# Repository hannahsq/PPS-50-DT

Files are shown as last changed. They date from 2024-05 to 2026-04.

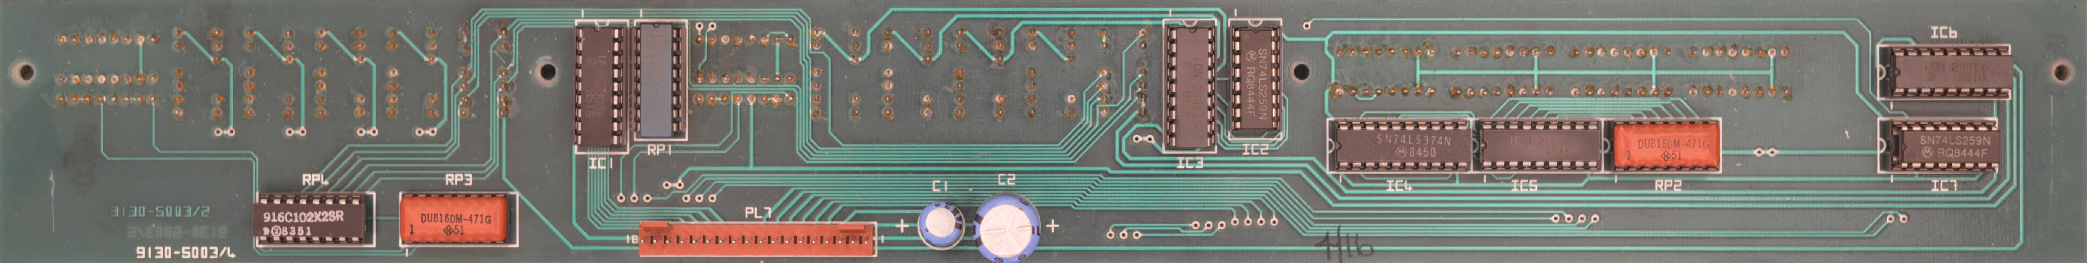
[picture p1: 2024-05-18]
pcb_photos/display_bottom.png

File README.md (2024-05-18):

# PPS-50-DT
Reverse engineered schematics and code for the Prism Instruments PPS 50 DT power supply

Everything is in a very rough state at the moment but I wanted to put this up there in case anyone finds it useful.

The disassembly is slow going, full of placeholder stuff, and likely riddled with mistakes. I will probably switch to ghidra from f9dasm when 6800 support is added.

The schematic is only partially complete but what is there should be mostly accurate.

## Disassembly
This project currently uses f9dasm (available [here][1]) and `disassemble.py` expects to find either f9dasm on linux or f9dasm.exe on windows at ../tools/f9dasm[.exe].

[1]: https://github.com/Arakula/f9dasm

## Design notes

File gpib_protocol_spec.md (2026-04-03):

# IEEE-488 (GPIB) Protocol Specification
## Reverse-Engineered from Firmware — Dual-Channel Power Supply

---

## 1. System Architecture

The instrument contains two 6802 processors connected via an optically-isolated UART link:

- **Primary Controller** — Manages the analog hardware: DACs, ADCs, analog switches,
  voltage/current regulation loops. Runs from 4K PROM.
- **GPIB Controller** — Handles all IEEE-488 bus communication. Contains an MC68488
  GPIA (General Purpose Interface Adapter) for GPIB bus management and an MC6850 ACIA
  for the inter-processor UART link.

The GPIB controller parses commands received over the IEEE-488 bus, translates them into
3-byte UART messages, sends them to the primary controller, receives 3-byte responses,
and formats the results back into GPIB response strings.

```
                 OPTOCOUPLERS
  IEEE-488       ┌──────────┐        ANALOG
  GPIB Bus ──── MC68488 ── ACIA ══════════ ACIA ── 6802 ──── DACs/ADCs
                 6802       │  UART LINK  │        Primary   Analog Switches
                 GPIB Ctrl  └──────────┘         Controller  Voltage/Current
```

## 2. GPIB Bus Configuration

- **Address**: Set by DIP switch (5-bit, bits 4:0 of MC68488 Address Register)
- **Capabilities**: Talk and Listen
- **Serial Poll**: Supported (status byte in MC68488 SPR, SRQ assertion)
- **Device Clear**: Supported (DCAS handling)
- **Termination**: Commands terminated by CR (0x0D), LF (0x0A), or EOI
- **Character set**: Alphanumeric (A-Z, a-z, 0-9), period (.), CR, LF only.
  Characters ` ' + , - / : ; \ ` and all control characters are rejected.
- **Max command length**: 50 characters

## 3. Command Reference

All commands are ASCII strings terminated by CR, LF, or EOI. Commands are
case-sensitive — set commands use lowercase letters.

### 3.1 Set Voltage

Set the output voltage for a channel.

| Command | Description |
|---|---|
| `aXXXX` | Set Channel A voltage |
| `bXXXX` | Set Channel B voltage |

`XXXX` is a decimal number. The firmware parses up to 4 digits and converts to a 16-bit
binary value which is sent to the primary controller's DAC. The exact voltage scaling
depends on the DAC and analog circuitry (needs to be determined from the hardware).

The GPIB talk response includes a decimal point: `VSA XX.XX` or `VSB XX.XX`.

**Examples:**
```
a1250    → Set Channel A voltage to 12.50 (units TBD)
b0500    → Set Channel B voltage to 05.00
```

### 3.2 Set Current

Set the output current / current limit for a channel.

| Command | Description |
|---|---|
| `cXXXX` | Set Channel A current |
| `dXXXX` | Set Channel B current |

Same numeric format as voltage commands. Response format: `ISA XX.XX` or `ISB XX.XX`.

### 3.3 Set Voltage Override

| Command | Description |
|---|---|
| `iXXXX` | Set Channel A voltage override |
| `jXXXX` | Set Channel B voltage override |

Response format: `VOA XX.XX` or `VOB XX.XX`.

The exact meaning of "override" vs "set" needs confirmation from the analog hardware,
but likely sets the voltage directly bypassing any tracking or limit logic.

### 3.4 Set Current Override

| Command | Description |
|---|---|
| `kXXXX` | Set Channel A current override |
| `lXXXX` | Set Channel B current override |

Response format: `IOA XX.XX` or `IOB XX.XX`.

### 3.5 Set Voltage Limit

| Command | Description |
|---|---|
| `eXXXX` | Set Channel A voltage limit |
| `fXXXX` | Set Channel B voltage limit |

Response format: `VLA XXXXX` or `VLB XXXXX` (no decimal point — 5 digit integer).

### 3.6 Set Current Limit

| Command | Description |
|---|---|
| `gXXXX` | Set Channel A current limit |
| `hXXXX` | Set Channel B current limit |

Response format: `ILA XXXXX` or `ILB XXXXX` (no decimal point — 5 digit integer).

### 3.7 Query Status

| Command | Description |
|---|---|
| `q` | Query full instrument status |

Returns a multi-field response string:

```
[ChA_mode]/[ChB_mode]/[tracking]/[output]<CR><LF+EOI>
```

**Channel mode fields** (4 characters each):

| String | Meaning |
|---|---|
| `A CV` | Channel A — Constant Voltage mode |
| `A CC` | Channel A — Constant Current mode |
| `A IL` | Channel A — Current Limit active |
| `A VL` | Channel A — Voltage Limit active |
| `B CV` | Channel B — Constant Voltage mode |
| `B CC` | Channel B — Constant Current mode |
| `B IL` | Channel B — Current Limit active |
| `B VL` | Channel B — Voltage Limit active |

**Tracking field** (4 characters):

| String | Meaning |
|---|---|
| `T ON` | Tracking mode enabled (channels linked) |
| `TOFF` | Tracking mode disabled |

**Output field** (4-5 characters):

| String | Meaning |
|---|---|
| `OPON`  | Output enabled |
| `OPOFF` | Output disabled |

**Example response:**
```
A CV/B CC/TOFF/OPON
```
This indicates Channel A is in constant voltage mode, Channel B is in constant current
mode, tracking is off, and the output is enabled.

### 3.8 Read Error Status

| Command | Description |
|---|---|
| `r` | Read error/status register |

Returns:
```
ER R [status]<CR><LF+EOI>
```

On success: `ER R OK`
On error: `ER R [code]!` where `[code]` is a single error character (see Section 5).

Reading the error status clears it back to "OK".

### 3.9 Unknown/Invalid Commands

If an unrecognised command character is received, the instrument responds with:

```
[cmd] ??<CR><LF+EOI>
```

Where `[cmd]` is the character that was sent.

## 4. Command-Response Lookup Table

The firmware contains an explicit mapping from command characters to 3-letter response
codes. This table is used when building GPIB talk responses after a set command:

| Command | Response Code | Full Meaning |
|---|---|---|
| `a` | `VSA` | Voltage Set A |
| `b` | `VSB` | Voltage Set B |
| `c` | `ISA` | Current Set A |
| `d` | `ISB` | Current Set B |
| `e` | `VLA` | Voltage Limit A |
| `f` | `VLB` | Voltage Limit B |
| `g` | `ILA` | Current Limit A |
| `h` | `ILB` | Current Limit B |
| `i` | `VOA` | Voltage Override A |
| `j` | `VOB` | Voltage Override B |
| `k` | `IOA` | Current Override A |
| `l` | `IOB` | Current Override B |

Set commands (`a`-`d`, `i`-`l`) respond with a decimal-pointed value: `CODE XX.XX`
Limit commands (`e`-`h`) respond with an integer value: `CODE XXXXX`

Leading zeros are suppressed in responses.

## 5. Error / Status Codes

Single-character status codes used internally between the two processors and reported
via GPIB serial poll and the `r` (read status) command:

| Code | Hex  | Meaning |
|---|---|---|
| `OK` | $4F4B | No error — normal operation |
| `I`  | $49 | Internal error (from primary controller) |
| `J`  | $4A | NMI hardware fault (from GPIB controller NMI handler) |
| `K`  | $4B | UART communication error (inter-processor link failure) |
| `M`  | $4D | Syntax error (invalid character in command) |
| `N`  | $4E | Value out of range (from primary controller) |
| `O`  | $4F | Command overflow (exceeded 50-character limit) |

### Serial Poll Status Byte

The instrument supports IEEE-488 serial polling. The serial poll response byte (MC68488
SPR register) contains the same single-character error code. When an error occurs:

1. The error code is written to the MC68488 Serial Poll Register
2. This asserts SRQ on the GPIB bus
3. The controller can serial-poll to read the status byte
4. After the poll is serviced, the status is cleared

The SRQ/poll mechanism is also used for status change notifications (e.g., when a
channel transitions between CV/CC modes).

## 6. Inter-Processor UART Protocol

### 6.1 Physical Layer

- **Baud rate**: Determined by MC6850 ACIA configuration — clock divider set to /16
- **Format**: 8 data bits, 2 stop bits, no parity
- **Isolation**: Optocoupler-isolated
- **Flow control**: Software (polling with timeout)

### 6.2 Message Format

All exchanges are 3 bytes in each direction, preceded by a handshake byte:

```
GPIB Controller → Primary Controller:
  [handshake: link_state_flags byte]
  [wait for acknowledgment]
  [byte 0: command character]
  [byte 1: data high byte]
  [byte 2: data low byte]

Primary Controller → GPIB Controller:
  [acknowledgment byte]
  [byte 0: command echo | 0x80 on error]
  [byte 1: response data high]
  [byte 2: response data low]
```

### 6.3 Handshake Protocol

1. GPIB controller sends `link_state_flags` byte
2. Primary controller echoes back with framing bits (masked by 0x30)
3. GPIB controller waits for echo with framing bits cleared
4. 3-byte command is sent
5. 3-byte response is received
6. Response byte 0 is compared against sent command (with bit 7 masked)
7. If mismatch, retry up to 5 times

### 6.4 Framing Byte Types

The UART link uses bits 5:4 of each byte to distinguish frame types:

| Bits 5:4 | Value | Meaning |
|---|---|---|
| `00` | $00 | Handshake acknowledgment (no framing) |
| `01` | $10 | Status frame (mode change notification) |
| `10` | $20 | Device status update (channel modes, tracking, output) |
| `11` | $30 | Link state update |

### 6.5 Asynchronous Status Updates

The primary controller can send unsolicited status updates to the GPIB controller
between command exchanges. These are received by the `uart_poll_rx` function in the
main loop:

- **Status update (0x20 frame)**: Carries the device status byte which encodes channel
  modes (CV/CC/IL/VL), tracking state, and output state.
- **Link state (0x30 frame)**: Carries link synchronisation state.
- **Error codes (0x10 frame with payload)**: Single-character error notifications
  ('I'=internal, 'J'=NMI, 'T'=talker, 'S'=serial poll).

### 6.6 Primary Controller Command Dispatch

The primary controller dispatches on the command byte (byte 0) minus 0x41 ('A') as an
index into a jump table. The command mapping is:

| Byte 0 Range | Jump Table Index | Function |
|---|---|---|
| `A`-`H` ($41-$48) | 0-7 | Set voltage/current (value in bytes 1:2) |
| `I`-`L` ($49-$4C) | 8-11 | Set limits |
| `Q` ($51) | 16 | Enable tracking |
| `R` ($52) | 17 | Disable tracking |
| `S` ($53) | 18 | Serial poll acknowledgment |
| `T` ($54) | 19 | Talker state update |
| `U` ($55) | 20 | Status update request |
| `V` ($56) | 21 | Device clear notification |
| `Y` ($59) | 24 | Enable output |
| `Z` ($5A) | 25 | Disable output |
| `a`-`l` ($61-$6C) | 32-43 | Readback (returns current actual values) |
| `q` ($71) | 48 | Query state |
| `r` ($72) | 49 | Read status |

## 7. Numeric Value Format

### 7.1 Input Parsing

Numeric arguments are parsed as decimal ASCII digit strings (up to 4 digits). The
firmware converts using a repeated-subtraction division algorithm with a powers-of-ten
table:

```
Powers: 10000 ($2710), 1000 ($03E8), 100 ($0064), 10 ($000A)
```

The resulting 16-bit binary value is transmitted to the primary controller in bytes 1:2
of the UART message (big-endian).

### 7.2 Output Formatting

For GPIB talk responses, 16-bit binary values from the primary controller are converted
back to decimal ASCII using the same powers-of-ten table. The format depends on the
command type:

- **Voltage/Current set commands** (a-d, i-l): `XX.XX` with decimal point after digit 2
- **Limit commands** (e-h): `XXXXX` as a plain integer

Leading zeros are suppressed (replaced with spaces).

## 8. Implementation Notes for Building a GPIB Controller

### 8.1 Minimum Viable Controller

To control the instrument over GPIB, a controller needs to:

1. Address the instrument as a listener
2. Send a command string terminated by CR or LF (with or without EOI)
3. For queries, address the instrument as a talker and read until EOI

### 8.2 Example Session

```
Controller → Instrument (Listen):  "a1250\r"     Set Ch A voltage to 12.50
Controller → Instrument (Talk):    reads →        "VSA 12.50\n" (with EOI)
Controller → Instrument (Listen):  "c0300\r"     Set Ch A current to 03.00
Controller → Instrument (Talk):    reads →        "ISA  3.00\n" (with EOI)
Controller → Instrument (Listen):  "q\r"         Query status
Controller → Instrument (Talk):    reads →        "A CV/B CV/TOFF/OPON\n"
Controller → Instrument (Listen):  "r\r"         Read error status
Controller → Instrument (Talk):    reads →        "ER R OK\n"
```

### 8.3 Timing Considerations

- The GPIB controller polls (not interrupt-driven for GPIB), so it will respond at the
  main loop rate.
- UART exchanges with the primary controller include a 0xFFFF-iteration timeout loop
  and up to 5 retries.
- The `q` (query) command waits for status synchronisation between the two processors
  before responding, which may introduce additional latency.

### 8.4 Unresolved Items

- **DAC value scaling**: The exact relationship between the numeric command values and
  physical voltage/current depends on the DAC resolution and analog front-end scaling.
  This needs to be determined from the hardware (DAC IC, reference voltage, op-amp gain).
- **"Override" commands (i-l)**: The distinction between "set" (a-d) and "override"
  (i-l) commands is not fully clear from firmware alone. Likely bypasses tracking or
  limit enforcement.
- **Front panel interaction**: The primary controller also handles keyboard/display via
  PIAs (IC18, IC19, IC20). GPIB commands and front panel controls may interact — the
  firmware appears to manage this via the M0x53 state byte.

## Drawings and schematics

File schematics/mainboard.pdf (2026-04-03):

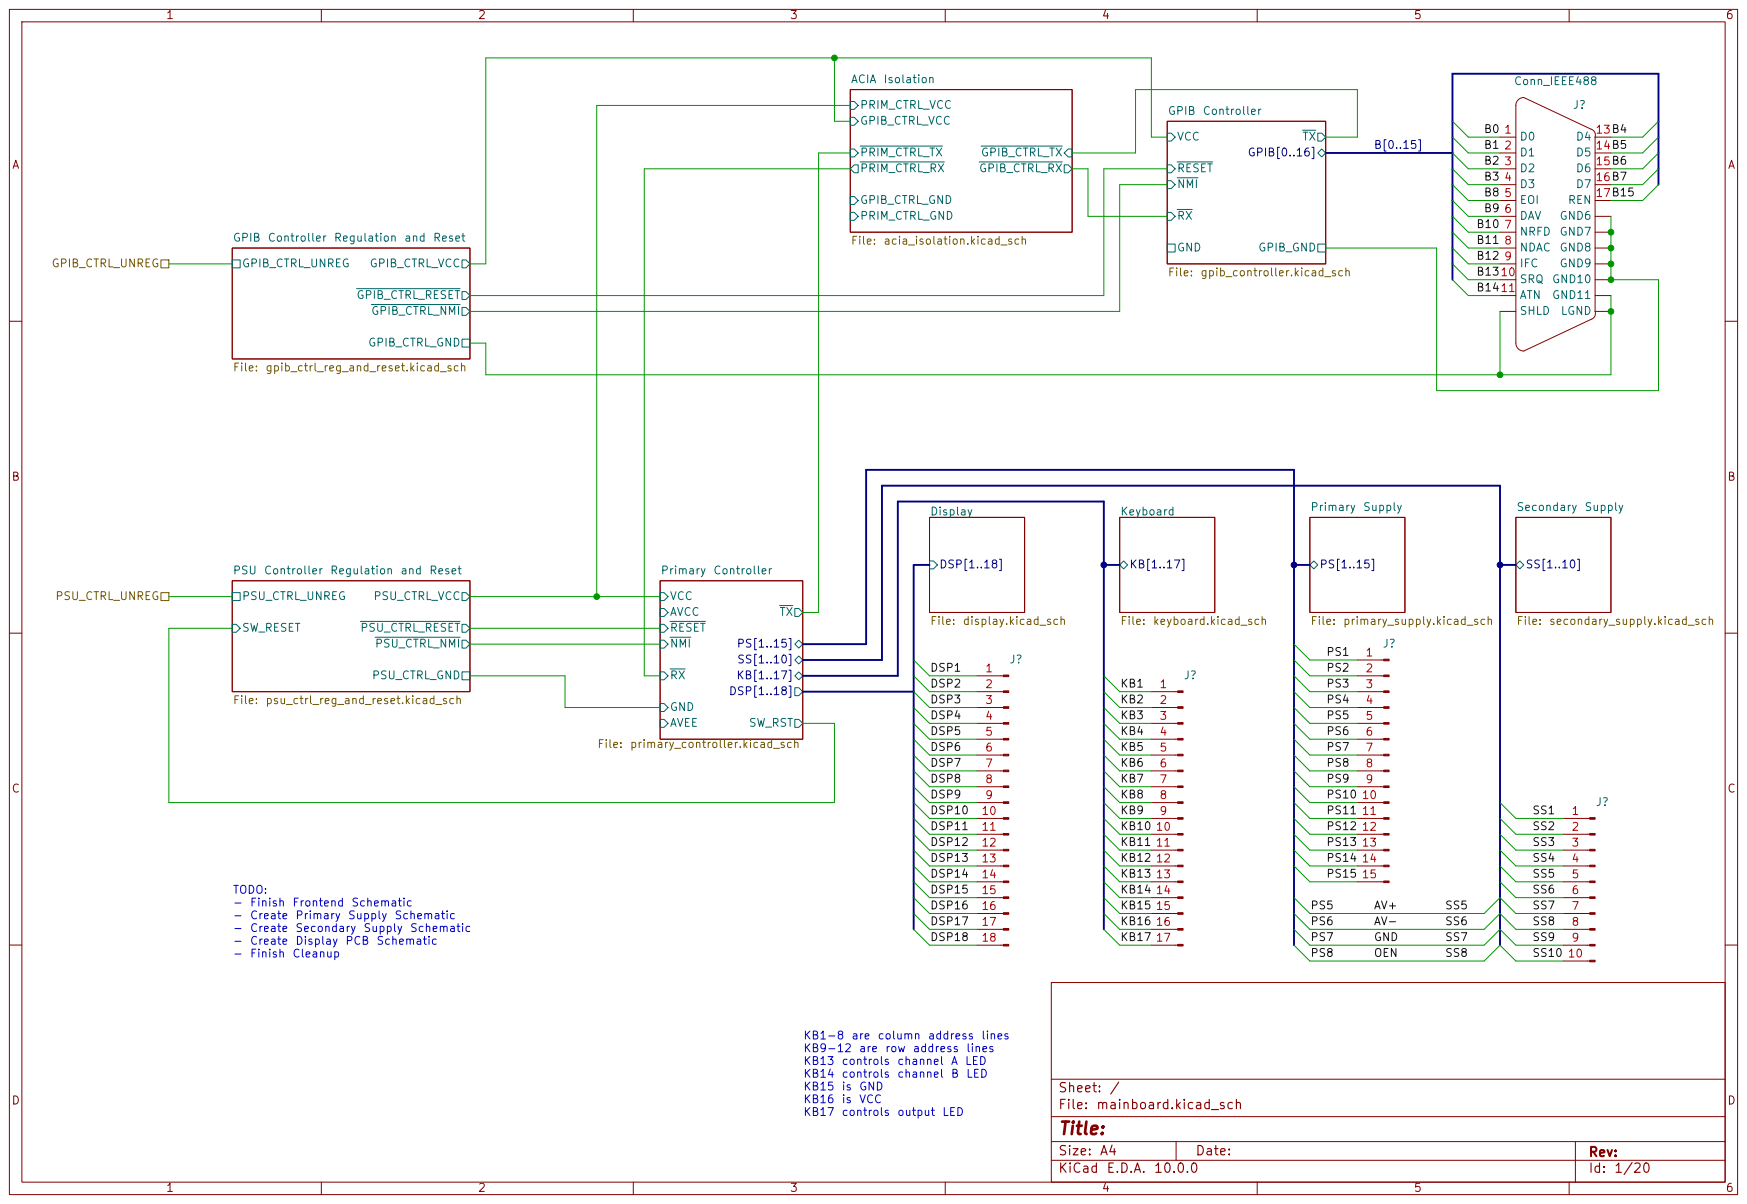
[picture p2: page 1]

RESET VCC NMI RX
AVCC
File: secondary_supply.kicad_sch GND

TODO: - Finish Frontend Schematic - Create Primary Supply Schematic - Create Secondary Supply Schematic - Create Display PCB Schematic - Finish Cleanup

KB1-8 are column address lines KB9-12 are row address lines KB13 controls channel A LED

Size: A4 | Rev:
KiCad E.D.A. 10.0.0 | Id: 1/20

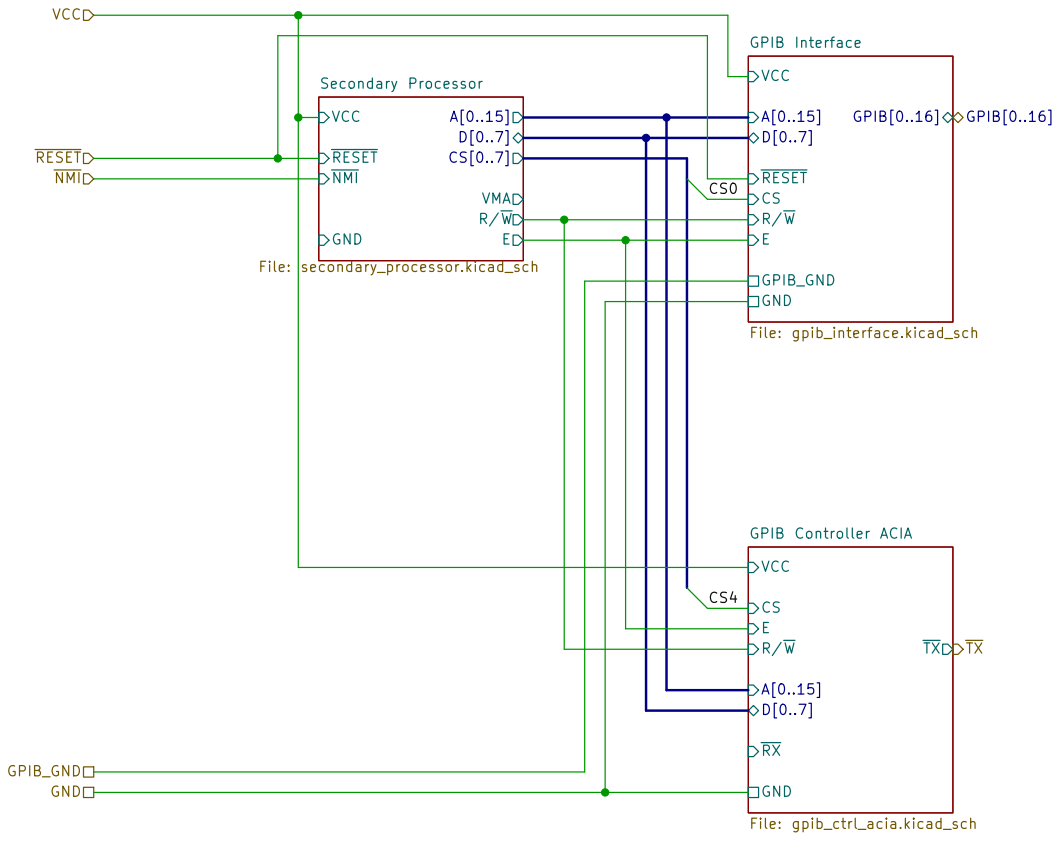
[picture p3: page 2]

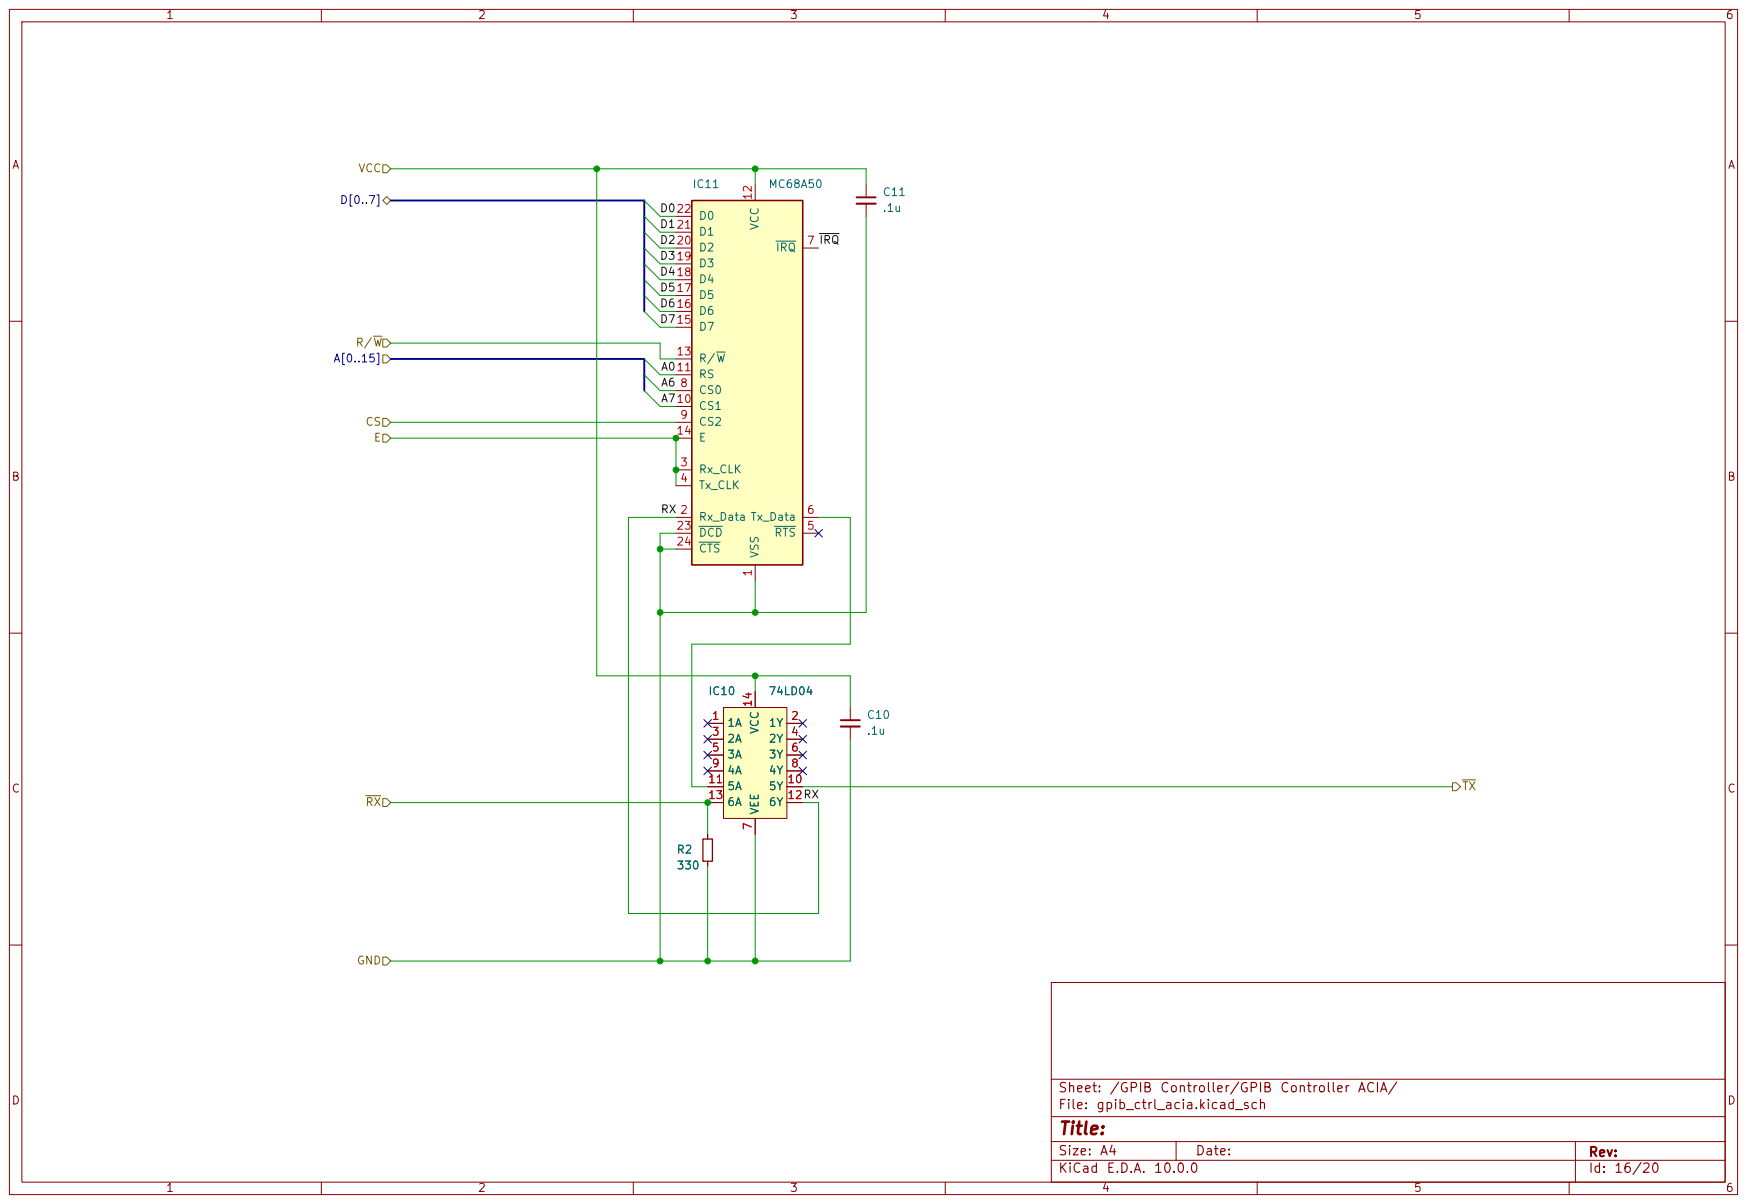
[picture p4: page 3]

Sheet: /GPIB Controller/GPIB Controller ACIA/
File: gpib_ctrl_acia.kicad_sch
Title:

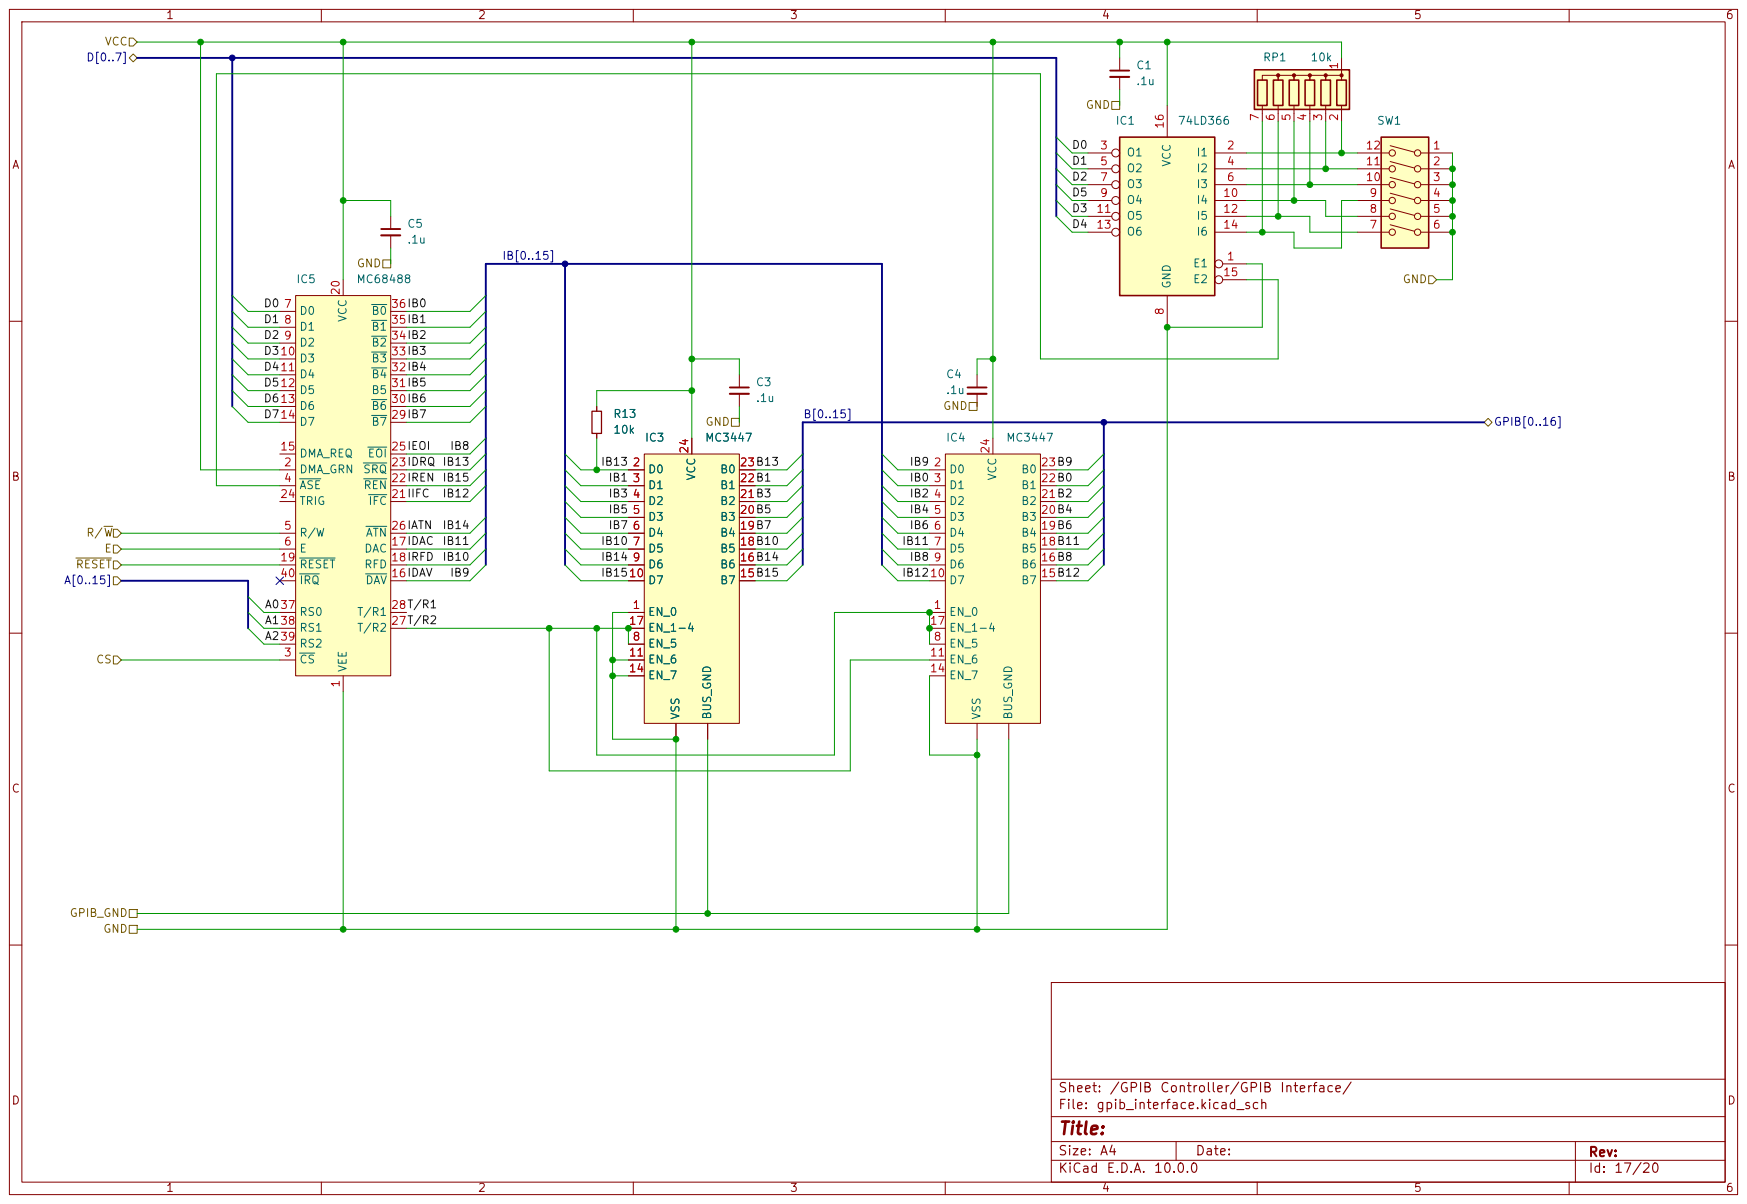
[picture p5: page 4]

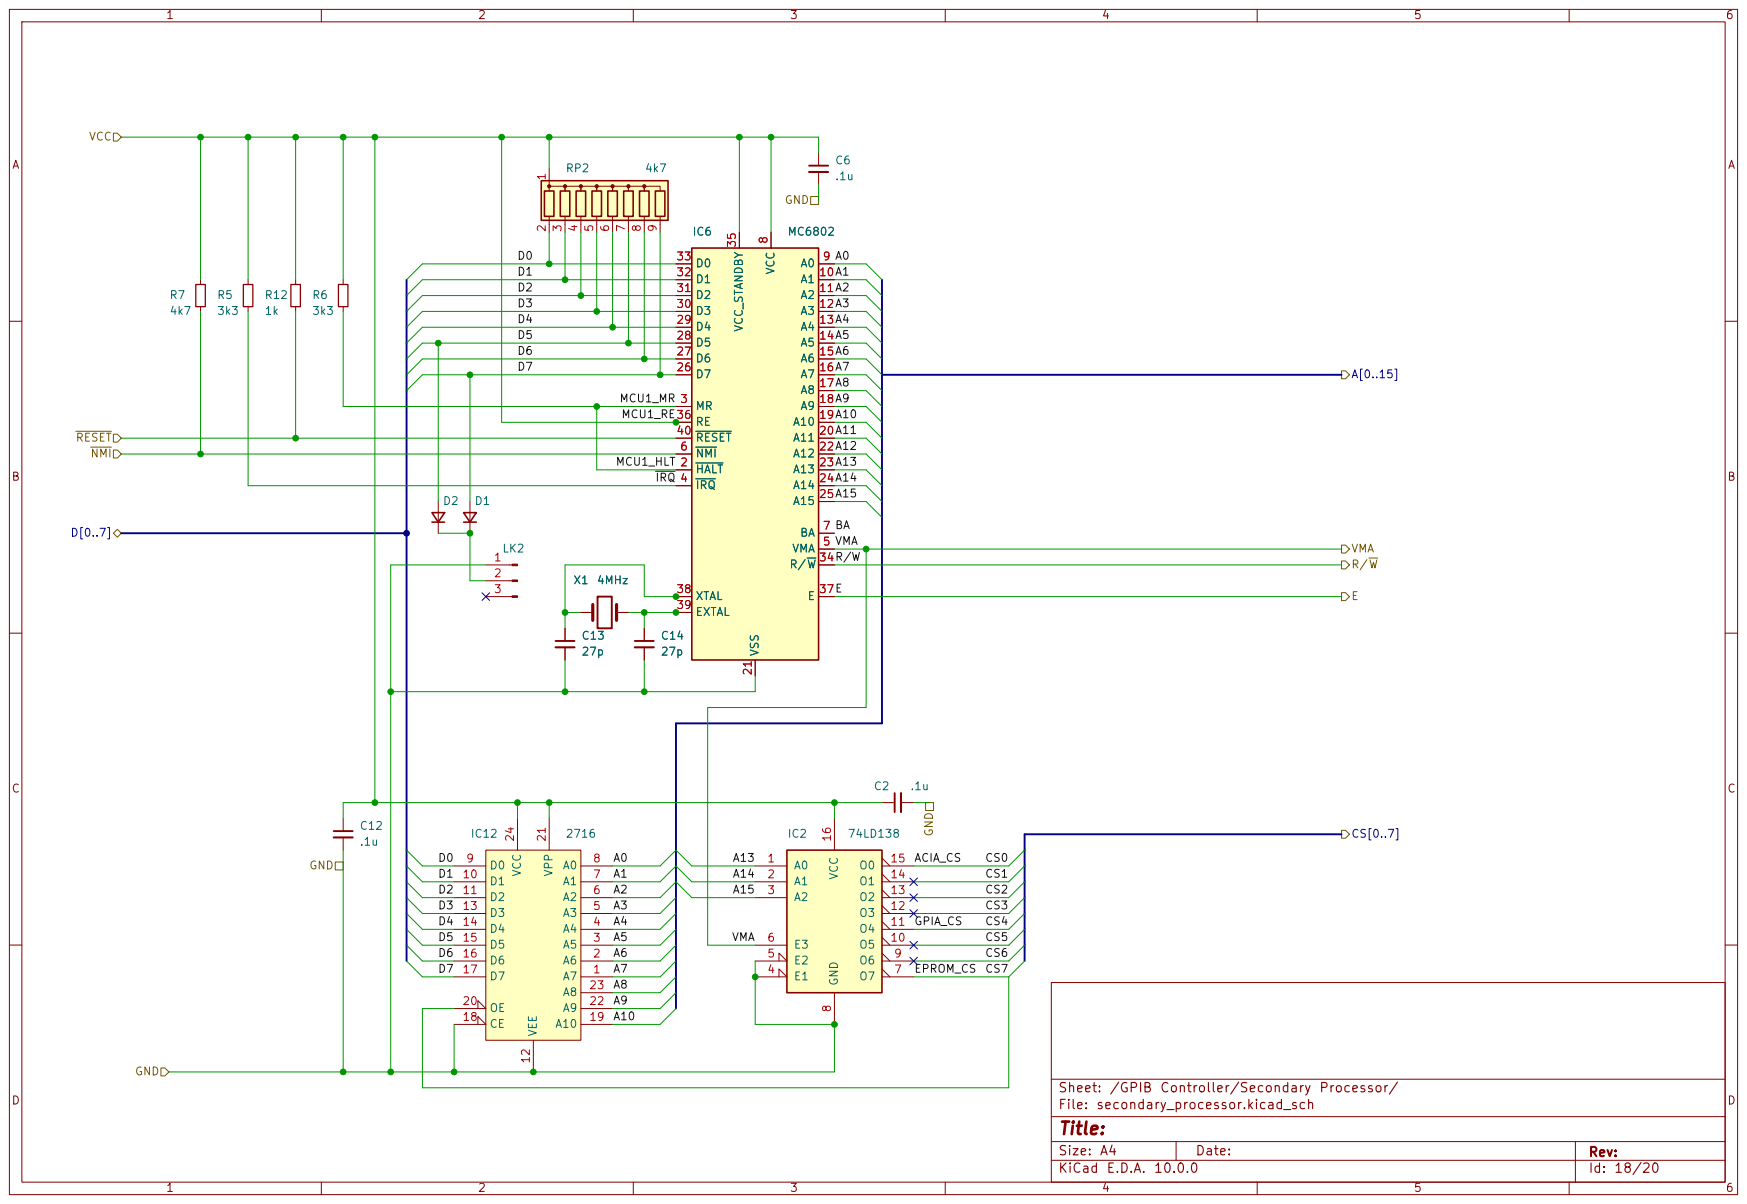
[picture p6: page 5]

Sheet: /GPIB Controller/Secondary Processor/
File: secondary_processor.kicad_sch
Title:

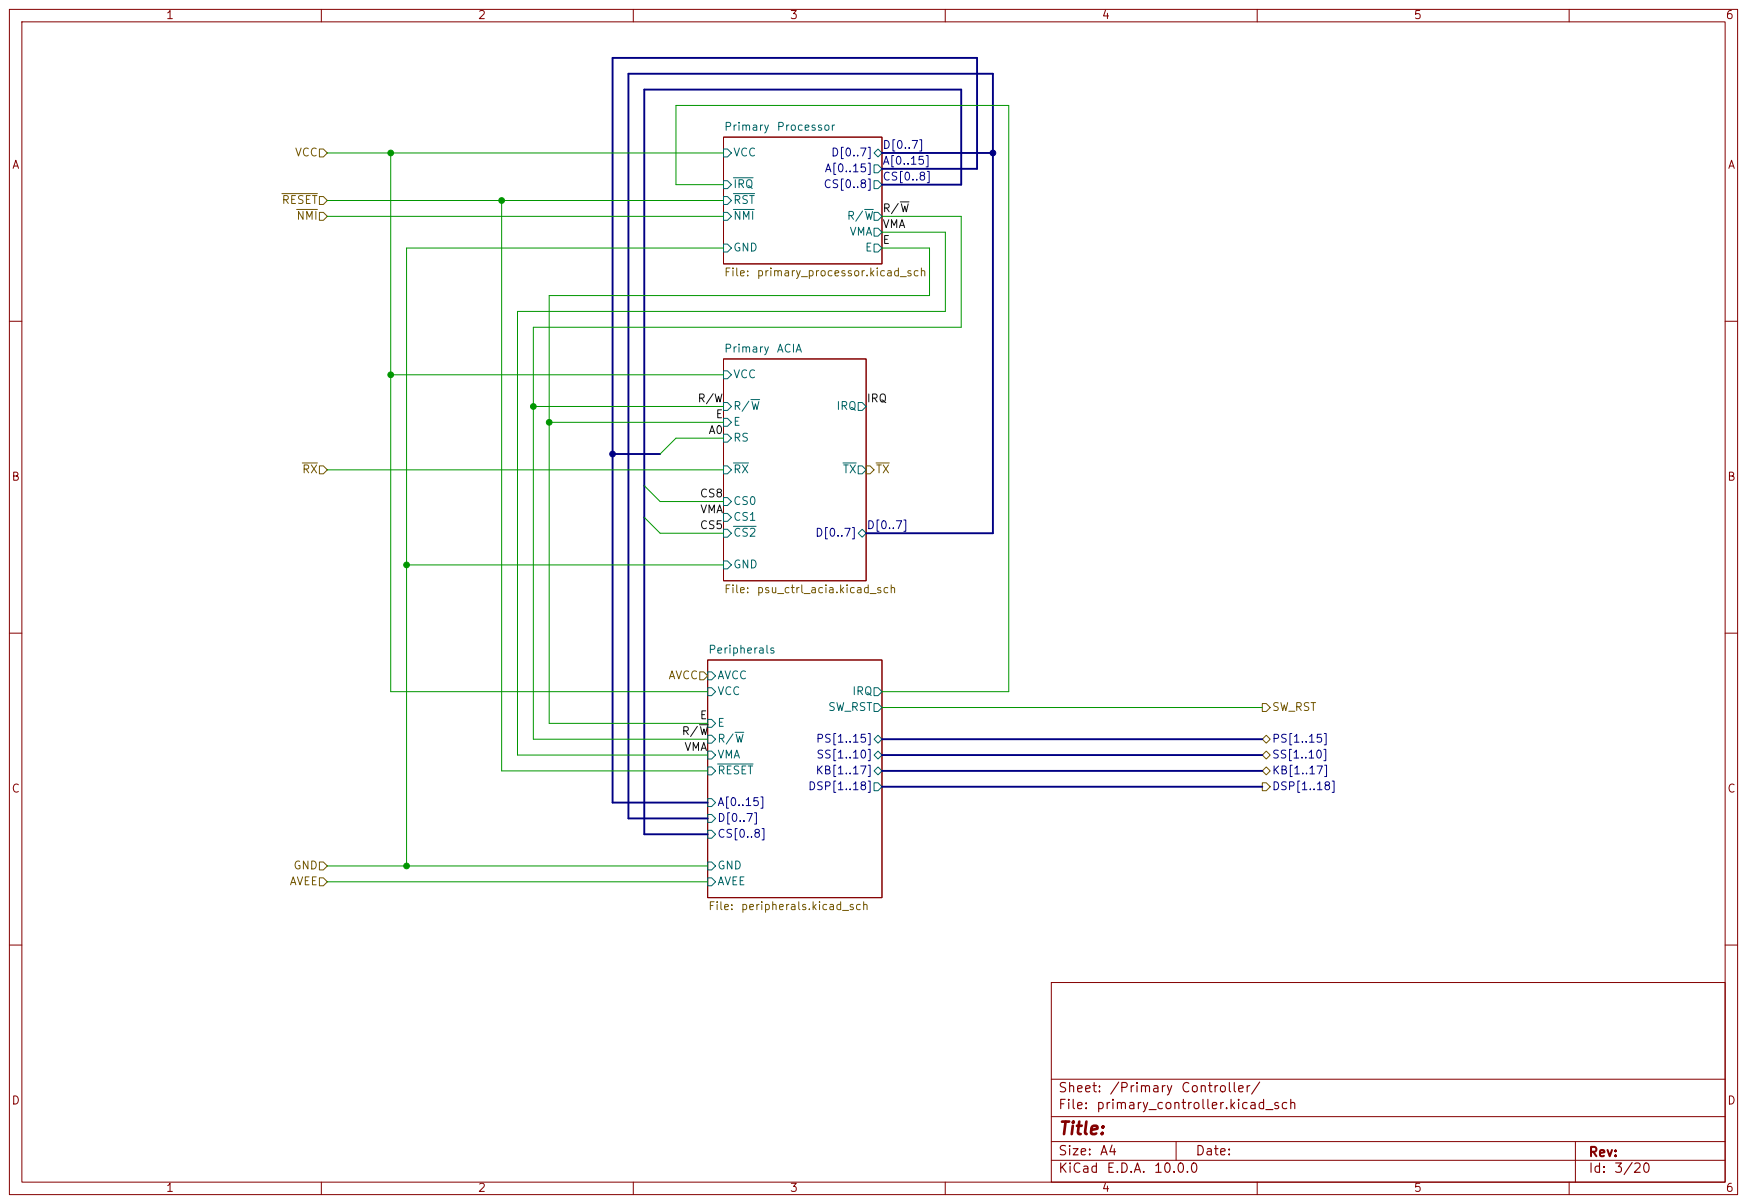
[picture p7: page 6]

NMI Primary Processor File: primary_processor.kicad_sch

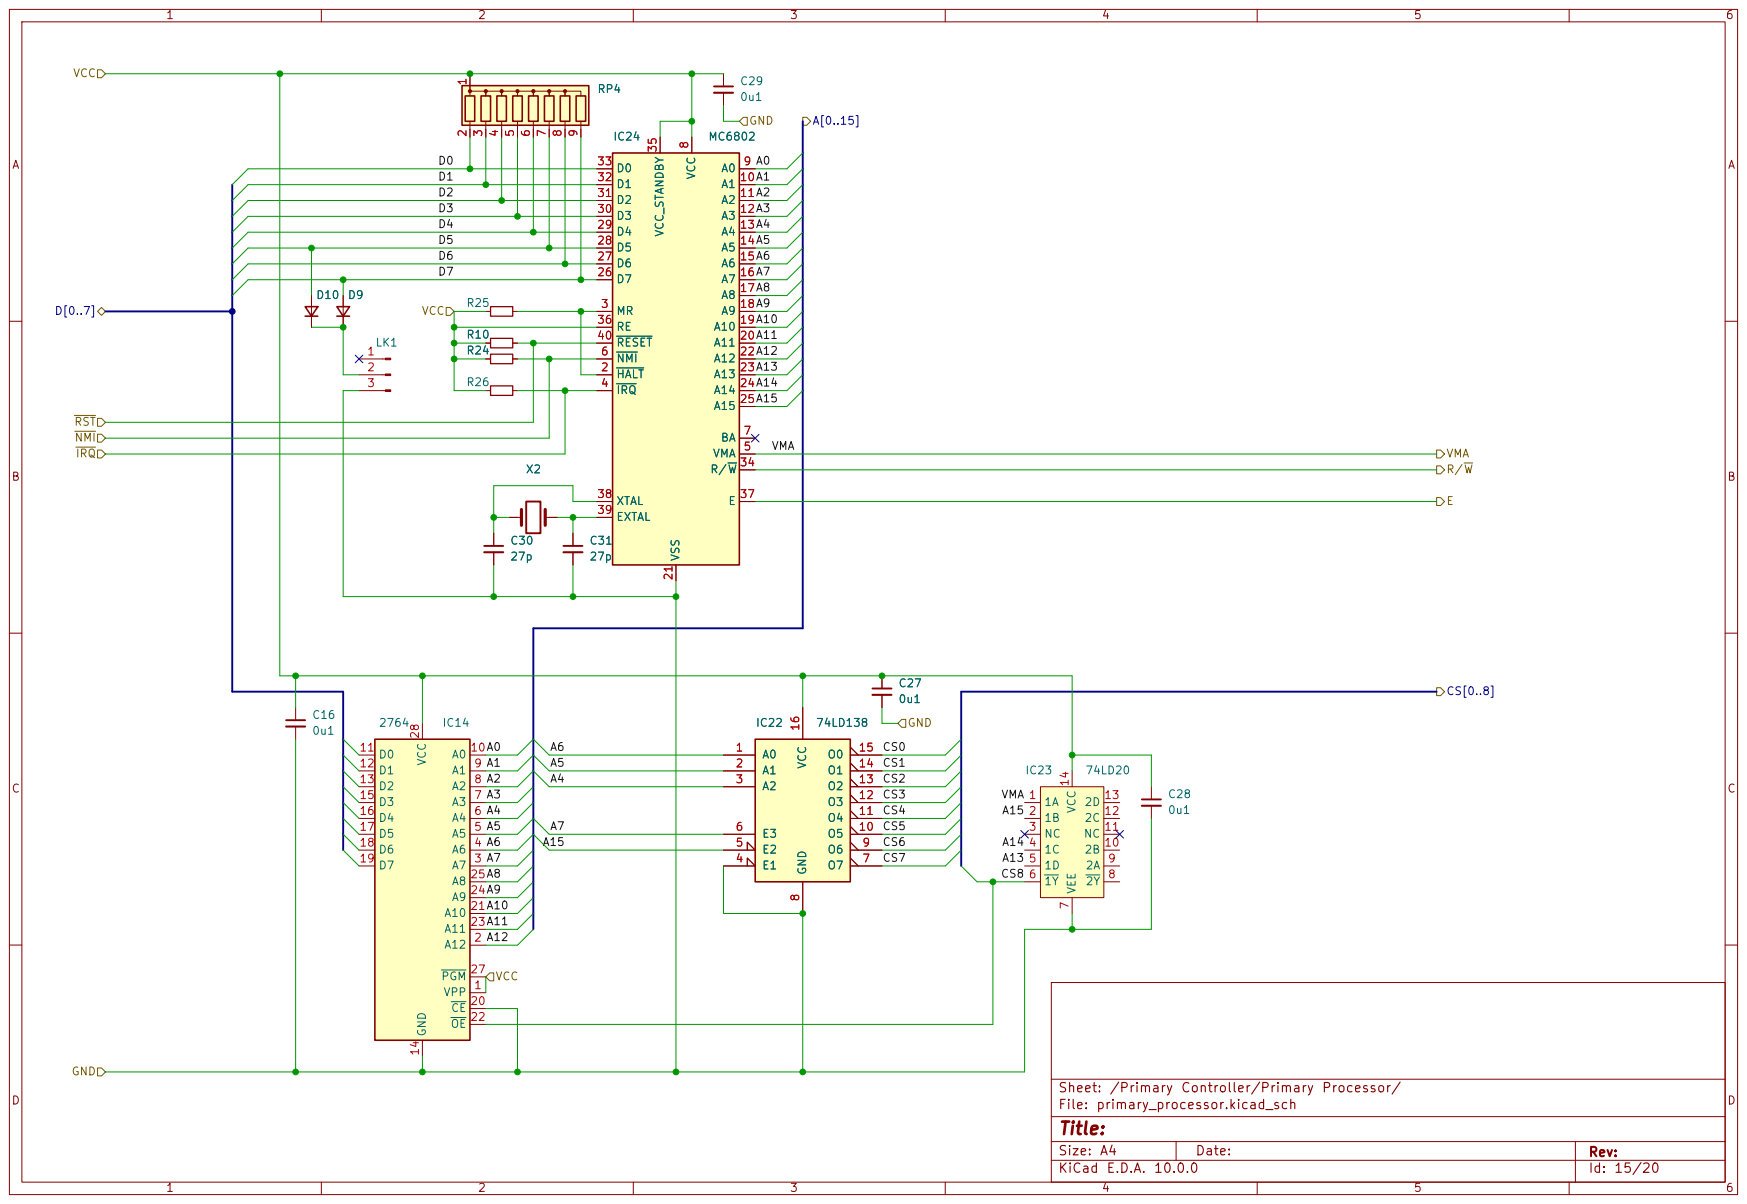
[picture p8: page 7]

Sheet: /Primary Controller/Primary Processor/
File: primary_processor.kicad_sch
Title:

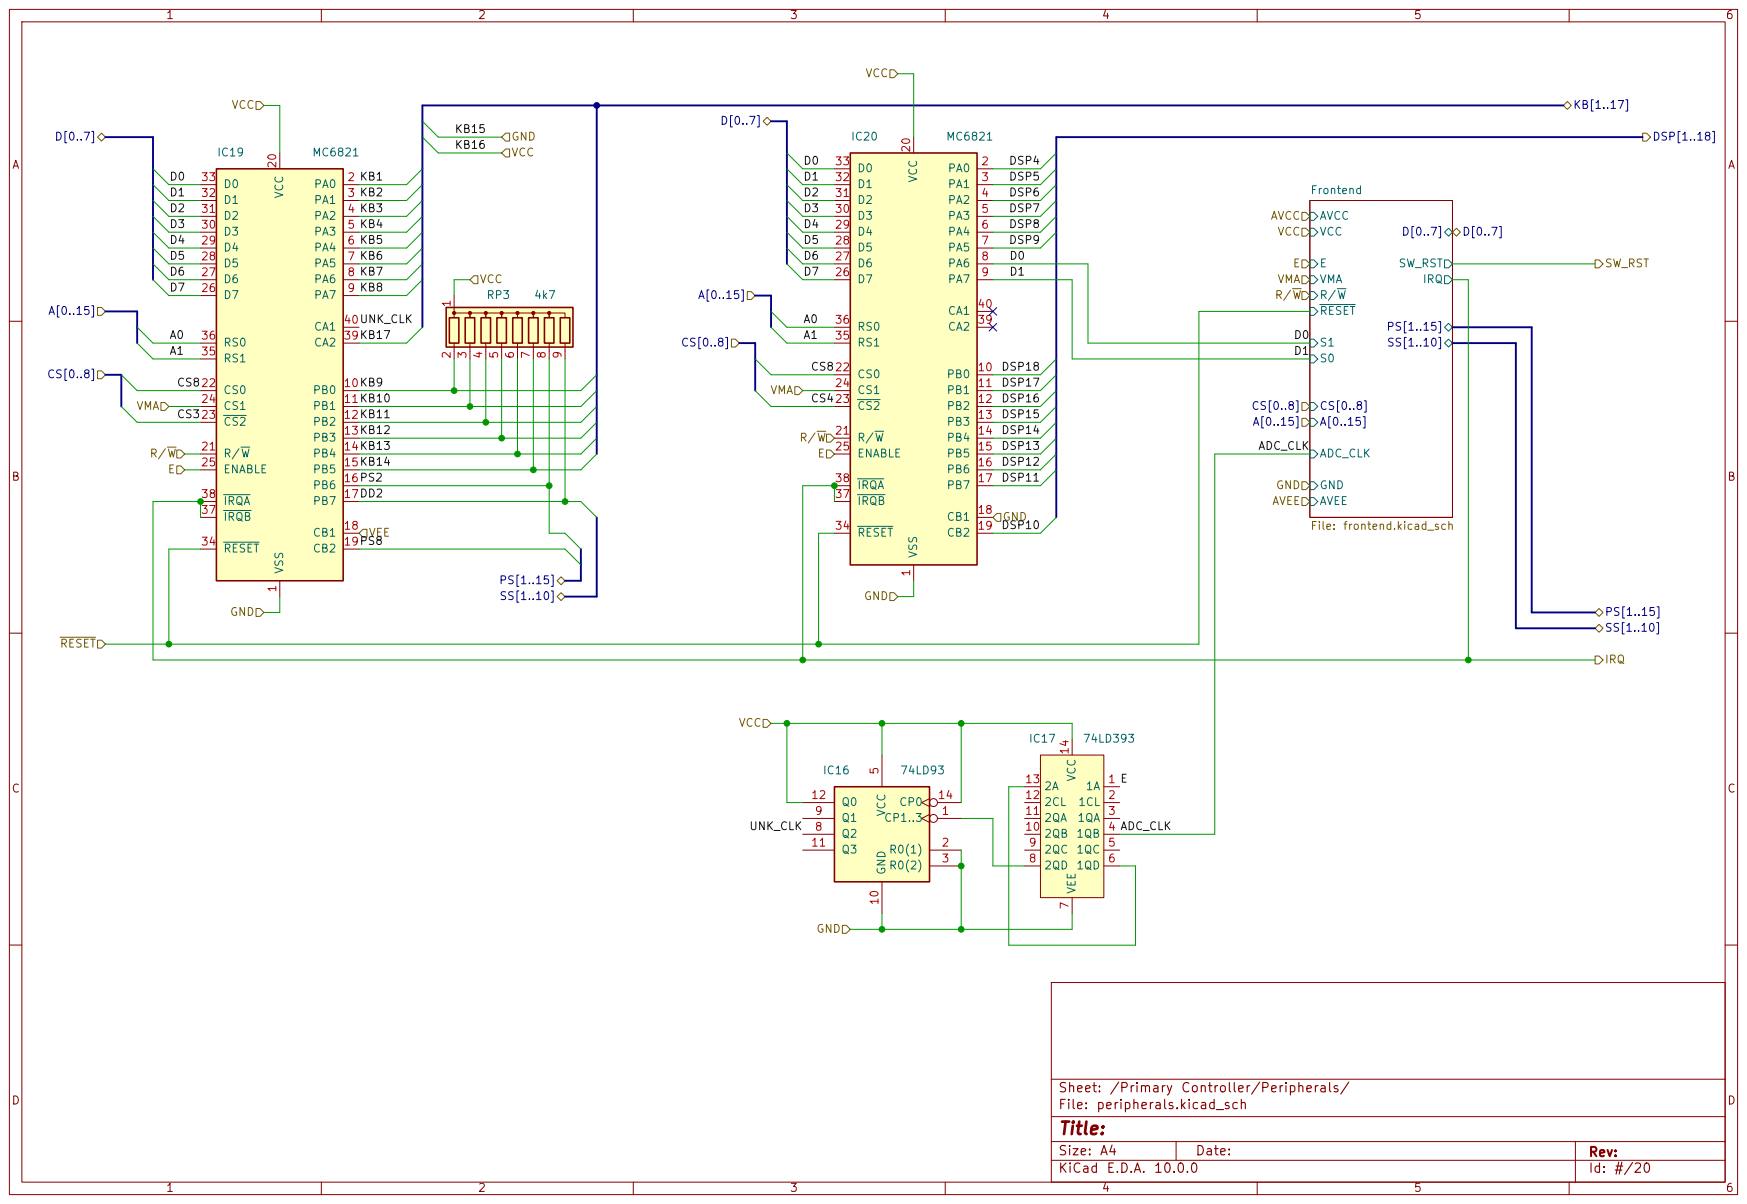
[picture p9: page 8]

Sheet: /Primary Controller/Peripherals/
File: peripherals.kicad_sch
Title:

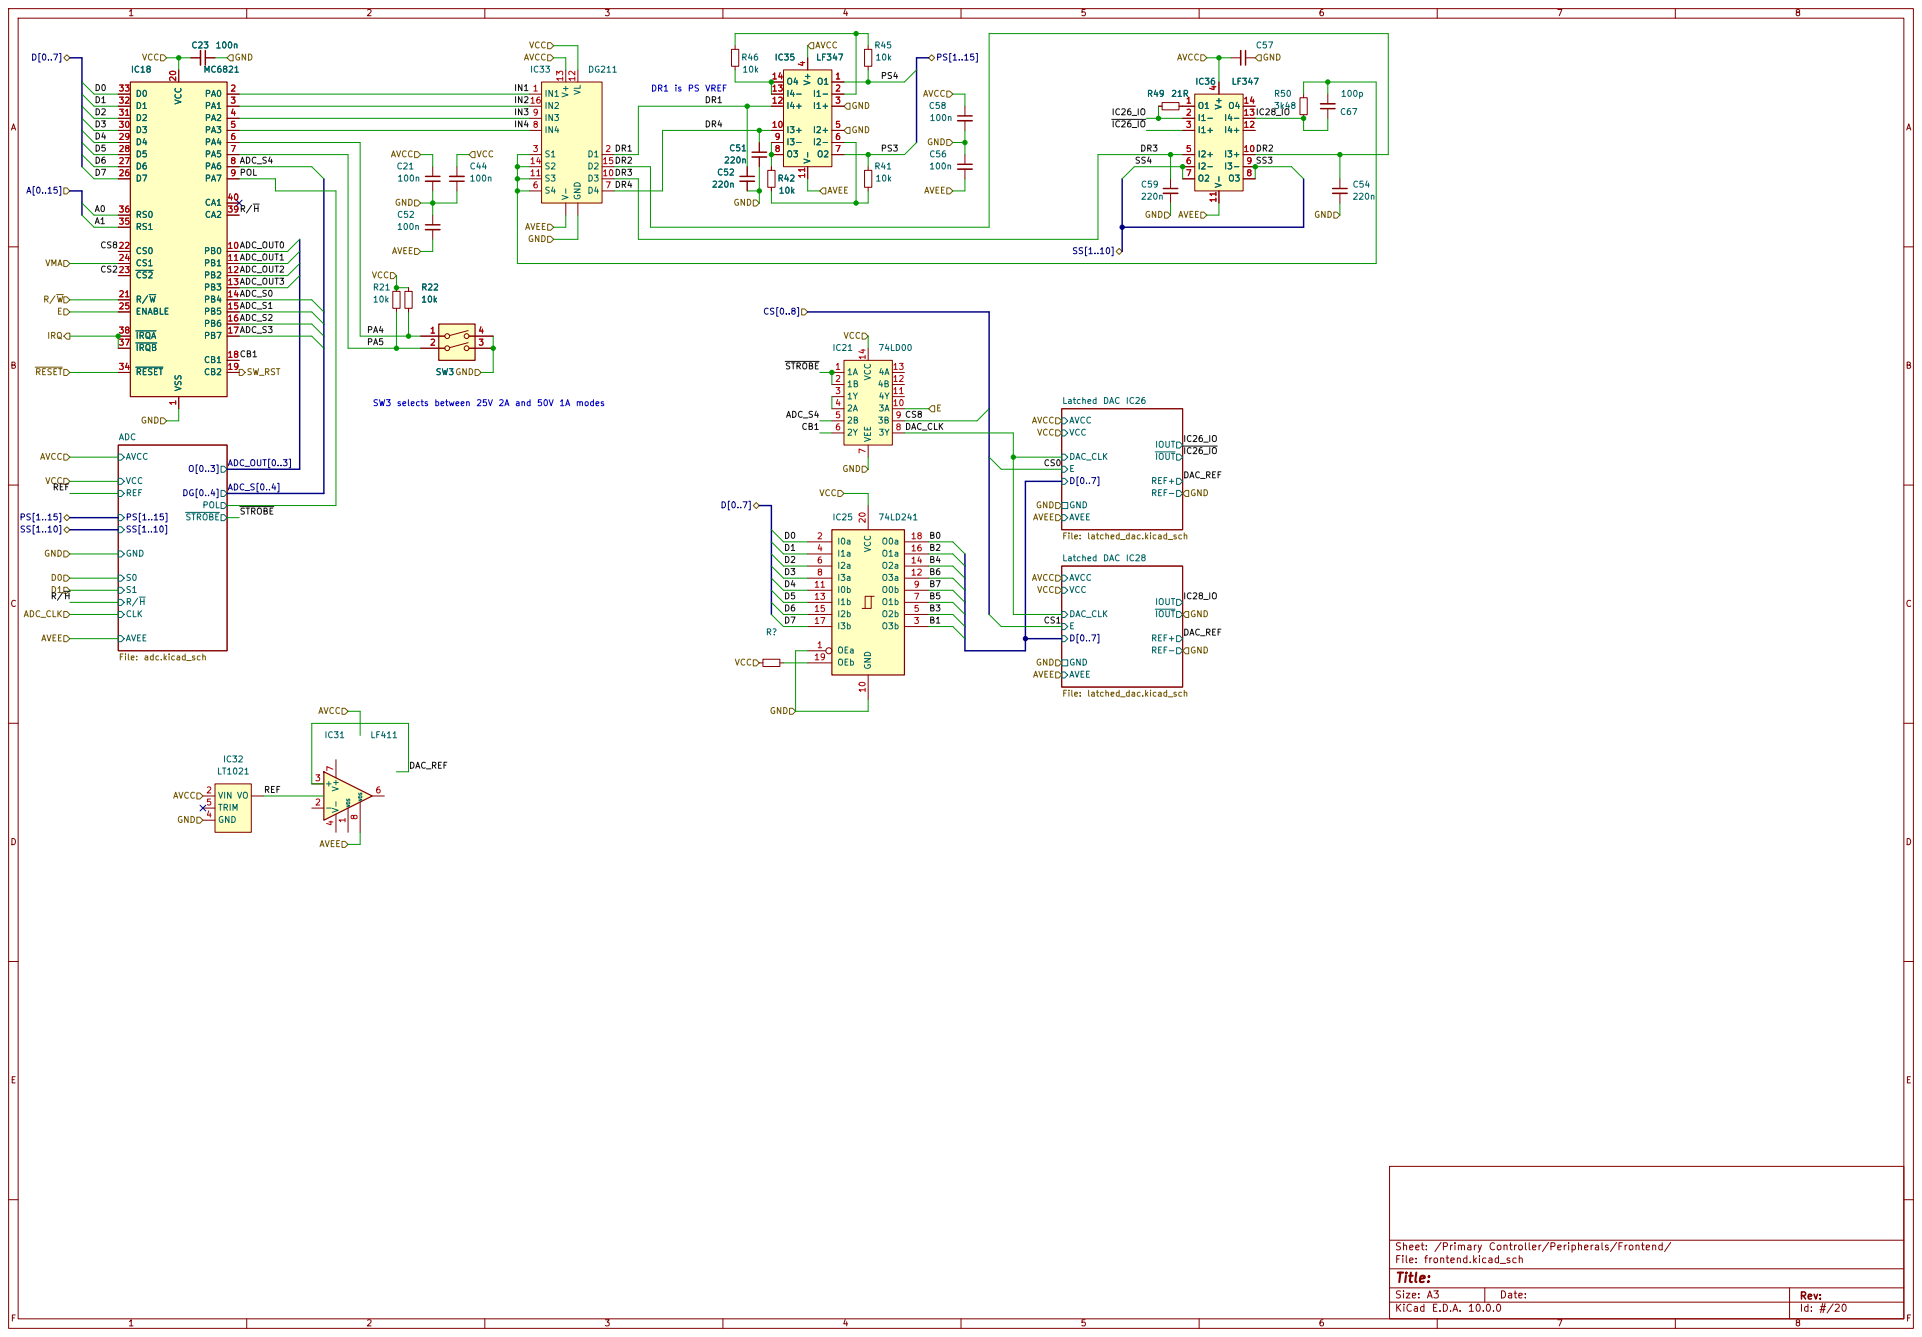
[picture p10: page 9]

Sheet: /Primary Controller/Peripherals/Frontend/
File: frontend.kicad_sch
Title:

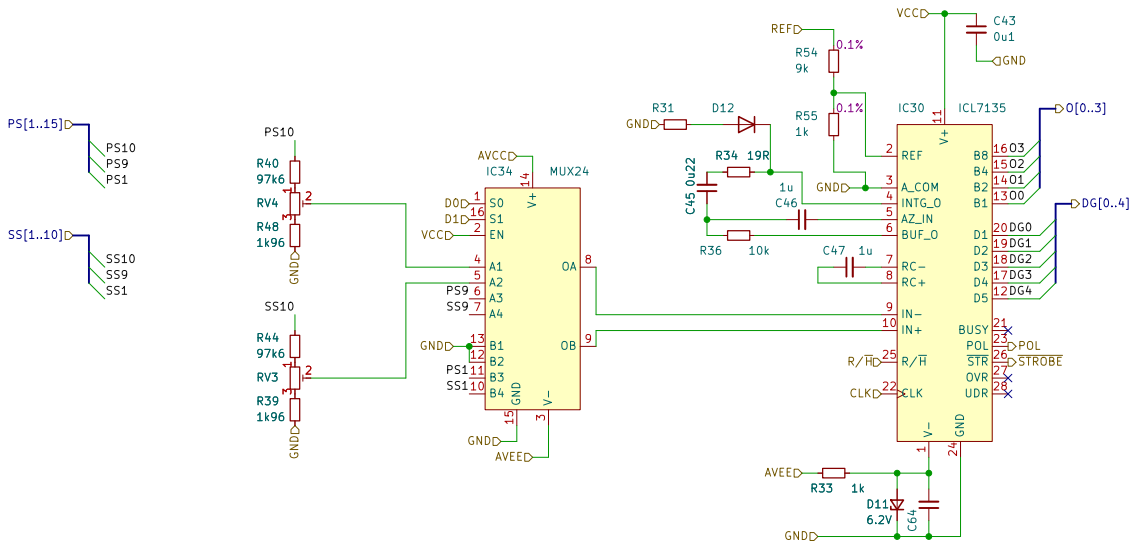
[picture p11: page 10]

Sheet: /Primary Controller/Peripherals/Frontend/ADC/ V-

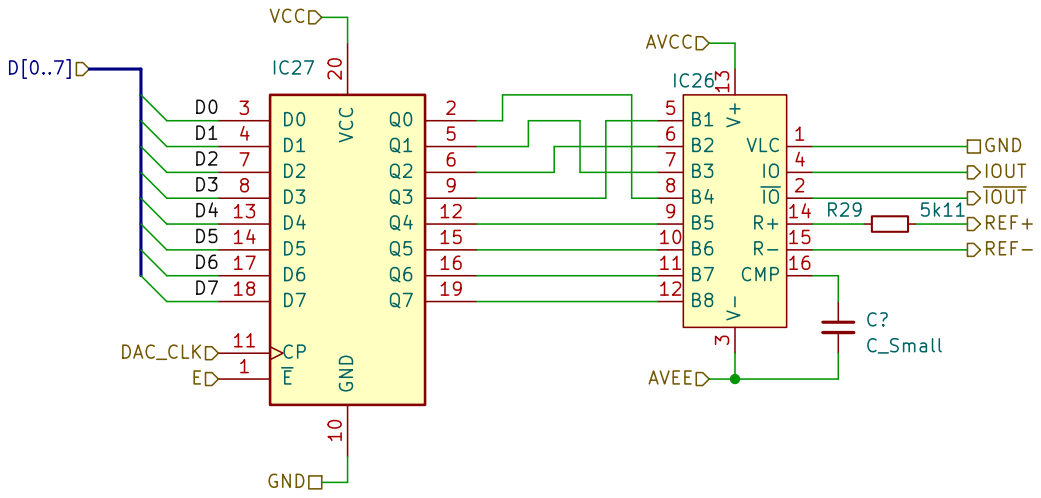
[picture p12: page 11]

Sheet: /Primary Controller/Peripherals/Frontend/Latched DAC IC26/
File: latched_dac.kicad_sch
Title:

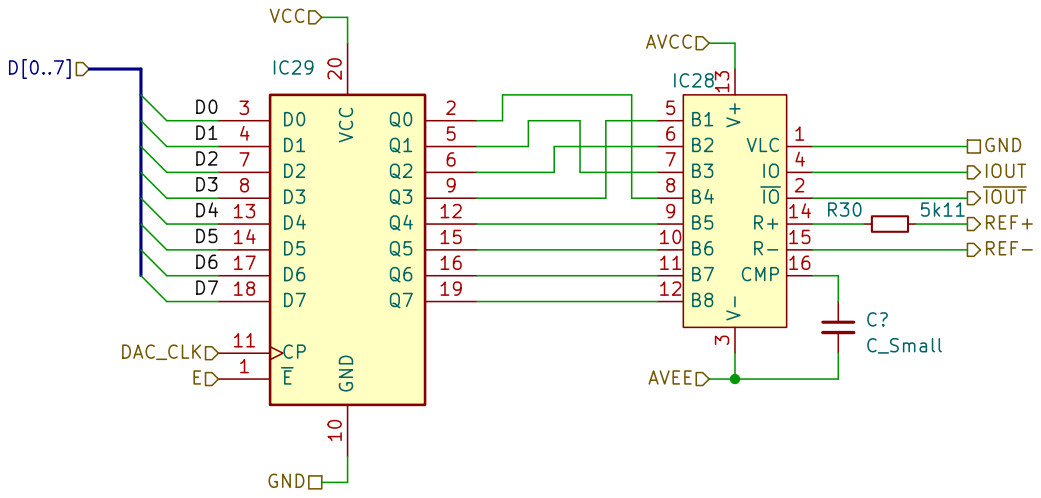
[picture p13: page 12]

Sheet: /Primary Controller/Peripherals/Frontend/Latched DAC IC28/
File: latched_dac.kicad_sch
Title:


3A 5
4A 9

Sheet: /Primary Controller/Primary ACIA/
File: psu_ctrl_acia.kicad_sch
Title:


Sheet: /PSU Controller Regulation and Reset/
File: psu_ctrl_reg_and_reset.kicad_sch
Title:


Sheet: /GPIB Controller Regulation and Reset/
File: gpib_ctrl_reg_and_reset.kicad_sch
Title:



TR3 is rsponsible for driving the relay

D_OUT1 = REAR IO V+ SENSE D_OUT2 = NC

PS4 is probably cc target/current limit reference voltage



4 | 13
5 | 12
6 | 11
7 | 10

I1 1
I2 2 GND | 10 | 7

I4 4 | | 12 | | 5
I5 5 | 13 | | | 4
I6 6 | | 14 | | 3
I7 7 | | | 15 | | 2
I8 8 | | | | | | 1

S[0..7] S7 DSP17 DSP15 DSP18 DSP16

4 | | 13 S3
6 | | 11 S5


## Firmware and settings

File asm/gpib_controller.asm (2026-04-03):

; f9dasm: M6800/1/2/3/8/9 / H6309 Binary/OS9/FLEX9 Disassembler V1.83
; Loaded binary file gpib_controller.bin
; Loaded binary file gpib_controller.bin

;****************************************************
;* Used Labels                                      *
;****************************************************

gpib_addr EQU     $0000
M0001   EQU     $0001
M0002   EQU     $0002
M0003   EQU     $0003
M0004   EQU     $0004
M0005   EQU     $0005
M0006   EQU     $0006
M0007   EQU     $0007
M0008   EQU     $0008
M0009   EQU     $0009
M000A   EQU     $000A
M000B   EQU     $000B
M000D   EQU     $000D
M000F   EQU     $000F
M0010   EQU     $0010
M0012   EQU     $0012
M0014   EQU     $0014
M0021   EQU     $0021
uart_tx_cmd EQU     $0022
uart_tx_data_hi EQU     $0023
uart_tx_data_lo EQU     $0024
link_state_flags EQU     $0025
spoll_status EQU     $0026
conv_workspace EQU     $0027
M0028   EQU     $0028
M0029   EQU     $0029
M002A   EQU     $002A
M002B   EQU     $002B
M002C   EQU     $002C
M002D   EQU     $002D
conv_accum_hi EQU     $0033
conv_accum_lo EQU     $0034
conv_digit_count EQU     $0035
conv_temp_hi EQU     $0036
conv_temp_lo EQU     $0037
conv_int_digit_count EQU     $0038
gpib_rx_char_count EQU     $0039
gpib_rx_buf_ptr_hi EQU     $003A
M003C   EQU     $003C
gpib_rx_error_flag EQU     $003D
uart_retry_count EQU     $003E
uart_rx_resp EQU     $003F
uart_rx_data_hi EQU     $0040
uart_rx_data_lo EQU     $0041
gpib_csr_snapshot EQU     $0042
dac_value_hi EQU     $0043
dac_value_lo EQU     $0044
device_status_confirmed EQU     $0045
device_status_pending EQU     $0046
error_code_hi EQU     $0047
error_code_lo EQU     $0048
gpib_eoi_flag EQU     $0049
current_gpib_cmd EQU     $004A
srq_pending EQU     $004B
gpib_line_complete EQU     $004C
gpib_tx_ptr_hi EQU     $004D
gpib_tx_last_byte EQU     $004F
STACK_TOP EQU     $007F
ACIA_CSR EQU     $00C0
ACIA_DR EQU     $00C1
STR_UNKNOWN_CMD EQU     $3F3F
STR_ER  EQU     $4552
STR_F_CR EQU     $460D
STR_FF  EQU     $4646
STR_OF  EQU     $4F46
STR_OK  EQU     $4F4B
STR_ON  EQU     $4F4E
STR_OP  EQU     $4F50
STR_R_SPACE EQU     $5220
STR_T_SPACE EQU     $5420
STR_TO  EQU     $544F
MC68488_ISR EQU     $8000
MC68488_CSR EQU     $8001
MC68488_ADSR EQU     $8002
MC68488_ACR EQU     $8003
MC68488_ADR EQU     $8004
MC68488_SPR EQU     $8005
MC68488_DR EQU     $8007

;****************************************************
;* Program Code / Data Areas                        *
;****************************************************

        ORG     $E000

; Set stack pointer to top of RAM
hdlr_RST LDS     #STACK_TOP               ;E000: 8E 00 7F       '...'
        LDAA    #$03                     ;E003: 86 03          '..'
; ACIA Master Reset (write 0x03 to CSR)
        STAA    ACIA_CSR                 ;E005: 97 C0          '..'
        LDAB    #$11                     ;E007: C6 11          '..'
; Configure ACIA: /16 clock, 8N2, RTS asserted, no interrupts
        STAB    ACIA_CSR                 ;E009: D7 C0          '..'
; Disable interrupts during init
        SEI                              ;E00B: 0F             '.'
; Clear all RAM ($0001-$007F)
        LDX     #STACK_TOP               ;E00C: CE 00 7F       '...'
        CLRA                             ;E00F: 4F             'O'
ZE010   STAA    ,X                       ;E010: A7 00          '..'
        DEX                              ;E012: 09             '.'
        BNE     ZE010                    ;E013: 26 FB          '&.'
; Reset MC68488 GPIA (set bit 7 of ACR)
        LDAA    #$80                     ;E015: 86 80          '..'
        STAA    MC68488_ACR              ;E017: B7 80 03       '...'
; Read GPIB address from DIP switch (ADR register)
        LDAA    MC68488_ADR              ;E01A: B6 80 04       '...'
; Mask to 5-bit address (bits 4:0)
        ANDA    #$1F                     ;E01D: 84 1F          '..'
; Store GPIB address in RAM
        STAA    gpib_addr                ;E01F: 97 00          '..'
; OR with $60 to disable talk/listen during setup
        ORAA    #$60                     ;E021: 8A 60          '.`'
; Write address to MC68488 ADR (talk+listen disabled)
        STAA    MC68488_ADR              ;E023: B7 80 04       '...'
; Clear Auxiliary Command Register
        CLR     MC68488_ACR              ;E026: 7F 80 03       '...'
; Clear Interrupt Status Register
        CLR     MC68488_ISR              ;E029: 7F 80 00       '...'
; Set MSA (Mode Select Auxiliary) bit
        LDAA    #$04                     ;E02C: 86 04          '..'
        STAA    MC68488_ACR              ;E02E: B7 80 03       '...'
; Clear ACR again (complete mode select sequence)
        CLR     MC68488_ACR              ;E031: 7F 80 03       '...'
; Clear Address Status/Mode Register
        CLR     MC68488_ADSR             ;E034: 7F 80 02       '...'
; Init GPIB RX buffer pointer to start (M0x01)
        LDX     #M0001                   ;E037: CE 00 01       '...'
        STX     gpib_rx_buf_ptr_hi       ;E03A: DF 3A          '.:'
; Init GPIB TX output pointer to start (M0x01)
        STX     gpib_tx_ptr_hi           ;E03C: DF 4D          '.M'
; Clear last-byte-sent register
        CLR     >gpib_tx_last_byte       ;E03E: 7F 00 4F       '..O'
; Re-read stored address
        LDAA    gpib_addr                ;E041: 96 00          '..'
; Write address with talk+listen enabled
        STAA    MC68488_ADR              ;E043: B7 80 04       '...'
; Load "OK" via immediate
        LDX     #STR_OK                  ;E046: CE 4F 4B       '.OK'
; Init error status to "OK"
        STX     error_code_hi            ;E049: DF 47          '.G'
; === MAIN LOOP START ===
; Check for status changes from primary controller
main_loop JSR     check_status_change      ;E04B: BD E6 FA       '...'
; Poll UART for incoming data from primary controller
        JSR     uart_poll_rx             ;E04E: BD E6 A0       '...'
; Check if link state needs synchronisation
        JSR     sync_link_state          ;E051: BD E7 6F       '..o'
; Clear CSR snapshot
        CLR     >gpib_csr_snapshot       ;E054: 7F 00 42       '..B'
; Read MC68488 Interrupt Status Register
        LDAA    MC68488_ISR              ;E057: B6 80 00       '...'
; Read MC68488 Command Status Register
        LDAB    MC68488_CSR              ;E05A: F6 80 01       '...'
; Store CSR in snapshot variable
        STAB    gpib_csr_snapshot        ;E05D: D7 42          '.B'
; Transfer ISR to condition codes via TAP:
; N=ISR.7 (SPC/RLC/DCAS), Z=ISR==0, V=ISR.6 (CO/ERR)
; C=ISR.0 (BI - Byte In)
        TAP                              ;E05F: 06             '.'
; Branch if no GPIB interrupts pending (Z=1)
        BEQ     poll_gpib_commands       ;E060: 27 03          ''.'
; GPIB interrupt active: enter receive handler
        JMP     gpib_receive_handler     ;E062: 7E E0 B1       '~..'
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

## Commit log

2022-07-02 Added WIP schematics and disassembly
2022-07-06 Moved more components into hierachical sheets, misc cleanup
    [adc.kicad_sch, frontend.kicad_sch, gpib_controller.kicad_sch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]
2022-07-06 cleanup, fixes, started on power supplies
    [acia_isolation.kicad_sch, adc.kicad_sch, frontend.kicad_sch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]
2024-05-18 More power supply work
    [acia_isolation.kicad_sch, adc.kicad_sch, display.kicad_sch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]
2024-05-18 Update to KiCad v8.0
    [acia_isolation.kicad_sch, adc.kicad_sch, display.kicad_sch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]
2024-05-18 Added pcb images
2026-04-03 Updated to KiCad v10.0. Minor improvements.
    [acia_isolation.kicad_sch, adc.kicad_sch, display.kicad_sch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]
2026-04-03 Added missing pcb photos and traced svgs of pcb traces.
